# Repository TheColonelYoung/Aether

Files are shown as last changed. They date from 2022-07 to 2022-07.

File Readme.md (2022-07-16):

# AETHER
Addressable LED controller powered by WLED. Sound reactive capable with IR receiver. Due to ESP32 is capable to produce FFT effects.
Designed as replacement electronics for SP511e. So it fits the same case.

### Features and components
- Compatible with 12V and 5V strips
- Built-on digital microphone (INMP411) 
    - Works with Sound reactive fork
    - Support FFT effects
- IR receiver for remote control
- Bootloader jumper
- 3 buttons for manual control

### SP511e replacement
This project is designed as replacement for SP511e electronics which is based on ESP8266 which is not capable of FFT effect and can only driver one line of LED strips.
You don't need to have SP511e controller but some part are salvageable. You can 3D print your own case.
Microphone is also replaced with digital omni-directional which has better results.

Some parts are salvageable from original board:
- Cables for LEDs
- IR receiver with cable
- Buttons
- Input power jack
- Case

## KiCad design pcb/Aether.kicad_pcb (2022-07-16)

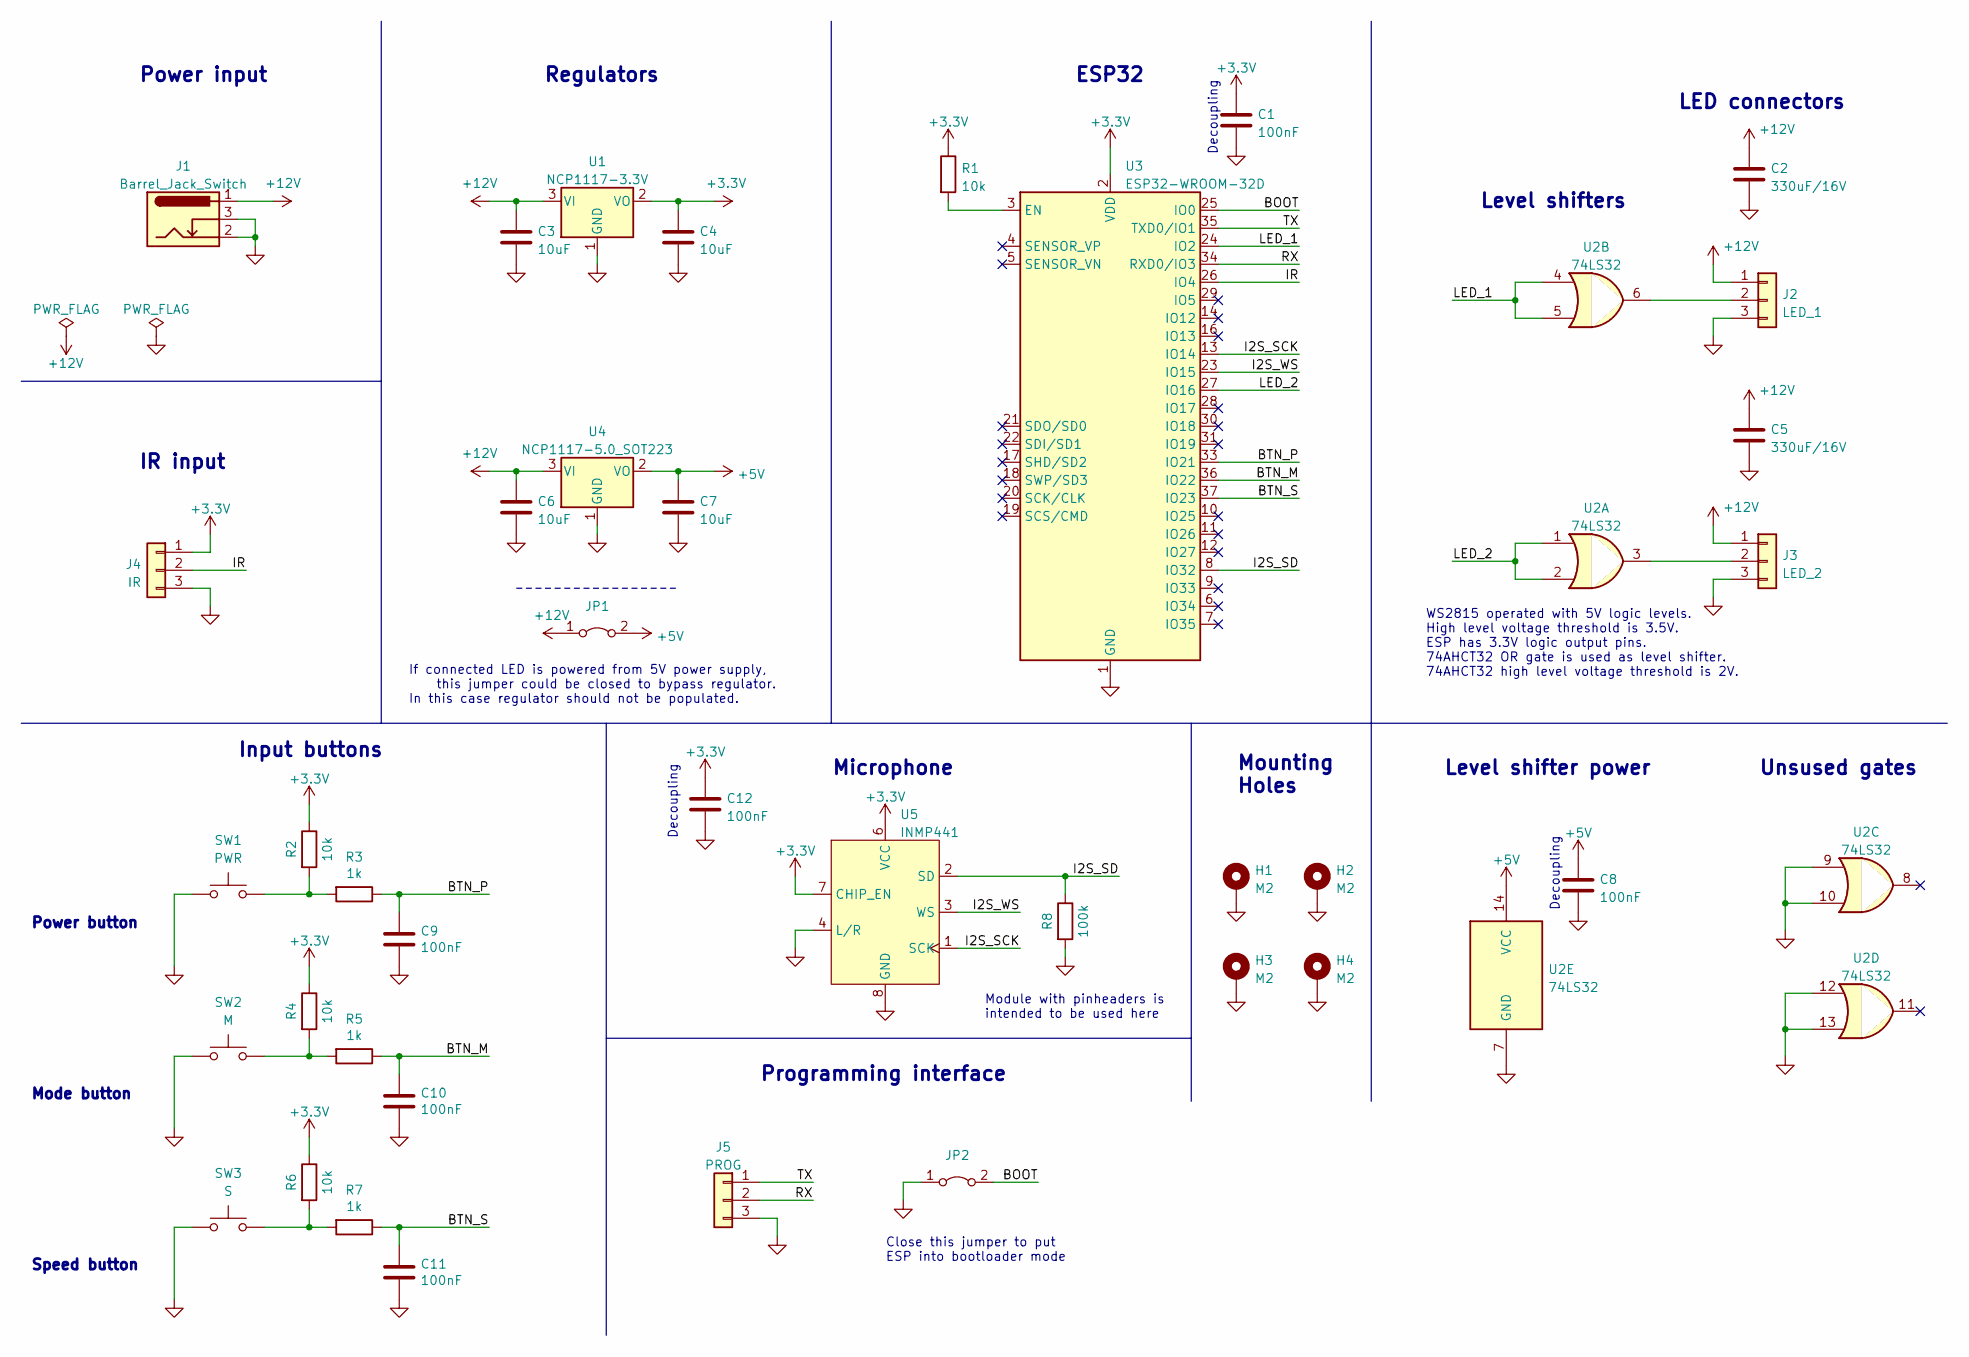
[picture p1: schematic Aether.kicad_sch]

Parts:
C1, C8, C9, C10, C11, C12: 100nF; C_0603_1608Metric
C2, C5: 330uF/16V; CP_Elec_6.3x7.7
C3, C4, C6, C7: 10uF; C_0805_2012Metric
H1, H2, H3, H4: M2; MountingHole_2.2mm_M2_Pad_Via
J1: Barrel_Jack_Switch; Barrel_jack_short
J2: LED_1; PinHeader_1x03_P2.54mm_Vertical
J3: LED_2; PinHeader_1x03_P2.54mm_Vertical
J4: IR; PinHeader_1x03_P2.54mm_Vertical
J5: PROG; PinHeader_1x03_P2.54mm_Vertical
JP1: 5V_PASSTHROUGH; SolderJumper-2_P1.3mm_Open_RoundedPad1.0x1.5mm
JP2: BOOT; PinHeader_1x02_P2.54mm_Vertical
R1, R2, R4, R6: 10k; R_0603_1608Metric
R3, R5, R7: 1k; R_0603_1608Metric
R8: 100k; R_0603_1608Metric
SW1: PWR; SW_SPST_TL3342
SW2: M; SW_SPST_TL3342
SW3: S; SW_SPST_TL3342
U1: NCP1117-3.3V; SOT-223-3_TabPin2
U2: 74LS32; Texas_S-PVQFN-N14
U3: ESP32-WROOM-32D; ESP32-WROOM-32
U4: NCP1117-5.0_SOT223; SOT-223-3_TabPin2
U5: INMP441

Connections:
+3.3V: C1.1, C4.1, C12.1, J4.1, R1.1, R2.1, R4.1, R6.1, U1.2 (VO), U3.2 (VDD), U5.6 (VCC), U5.7 (CHIP_EN)
+5V: C7.1, C8.1, JP1.2 (B), U2.14 (VCC), U4.2 (VO)
+12V: C2.1, C3.1, C5.1, C6.1, J1.1, J2.1, J3.1, JP1.1 (A), U1.3 (VI), U4.3 (VI)
/BOOT: JP2.2 (B), U3.25 (IO0)
/BTN_M: C10.1, R5.1, U3.36 (IO22)
/BTN_P: C9.1, R3.1, U3.33 (IO21)
/BTN_S: C11.1, R7.1, U3.37 (IO23)
/I2S_SCK: U3.13 (IO14), U5.1 (SCK)
/I2S_SD: R8.1, U3.8 (IO32), U5.2 (SD)
/I2S_WS: U3.23 (IO15), U5.3 (WS)
/IR: J4.2, U3.26 (IO4)
/LED_1: U2.4, U2.5, U3.24 (IO2)
/LED_2: U2.1, U2.2, U3.27 (IO16)
/RX: J5.2, U3.34 (RXD0/IO3)
/TX: J5.1, U3.35 (TXD0/IO1)
GND: C1.2, C2.2, C3.2, C4.2, C5.2, C6.2, C7.2, C8.2, C9.2, C10.2, C11.2, C12.2, H1.1, H2.1, H3.1, H4.1, J1.2, J1.3, J2.3, J3.3, J4.3, J5.3, JP2.1 (A), R8.2, SW1.1, SW2.1, SW3.1, U1.1 (GND), U2.7 (GND), U2.9, U2.10, U2.12, U2.13, U3.1 (GND), U3.15 (GND), U3.38 (GND), U3.39 (GND), U4.1 (GND), U5.4 (L/R), U5.5 (GND), U5.8 (GND), U5.9 (GND)
unnamed: J2.2, U2.6
unnamed: J3.2, U2.3
unnamed: R1.2, U3.3 (EN)
unnamed: R2.2, R3.2, SW1.2
unnamed: R4.2, R5.2, SW2.2
unnamed: R6.2, R7.2, SW3.2

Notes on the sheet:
Regulators
IR input
WS2815 operated with 5V logic levels. High level voltage threshold is 3.5V. ESP has 3.3V logic output pins. 74AHCT32 OR gate is used as level shifter. 74AHCT32 high level voltage threshold is 2V.
Decoupling
Level shifter power
Input buttons
Power button
Level shifters
Programming interface
LED connectors
ESP32
Mounting Holes
Power input
Close this jumper to put ESP into bootloader mode
Microphone
If connected LED is powered from 5V power supply, this jumper could be closed to bypass regulator. In this case regulator should not be populated.
Module with pinheaders is intended to be used here
Unsused gates
Speed button
Mode button

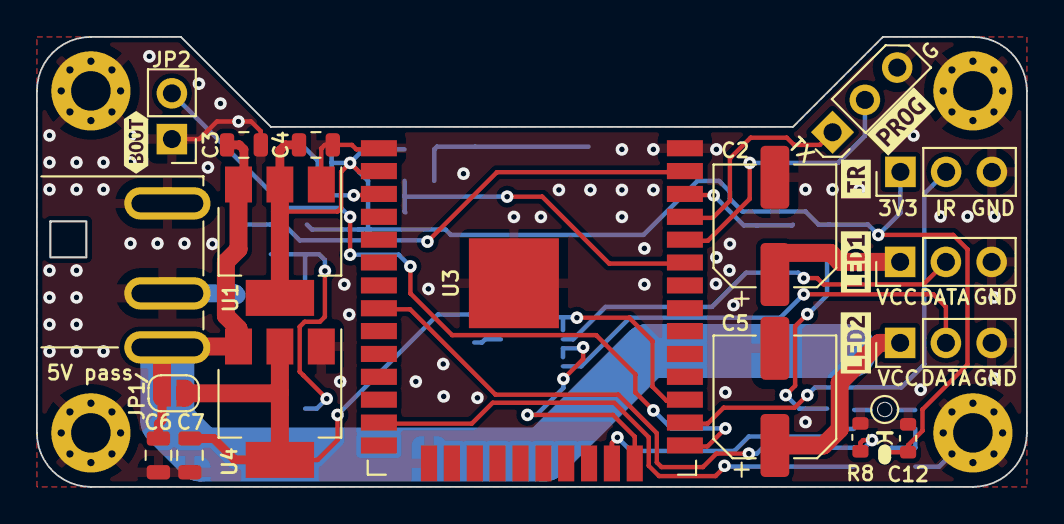
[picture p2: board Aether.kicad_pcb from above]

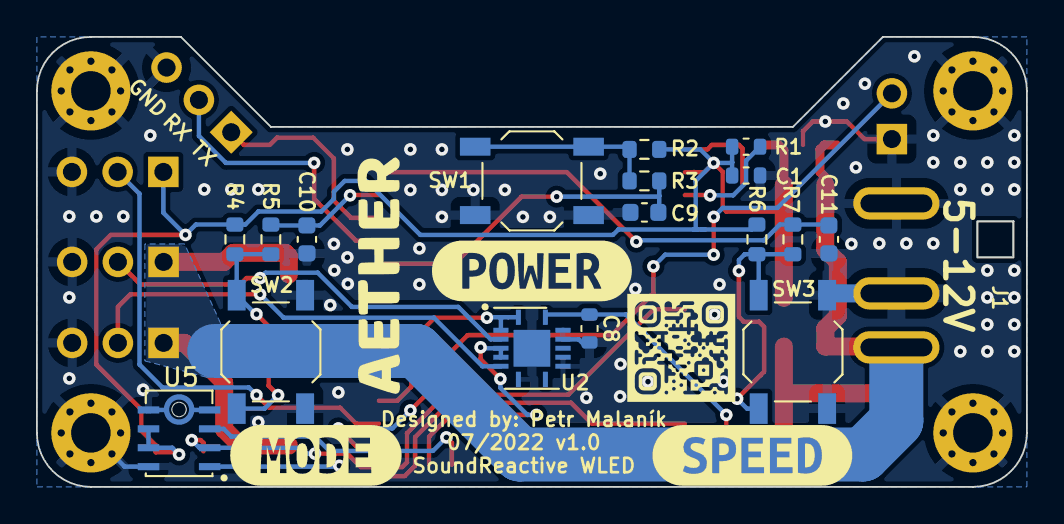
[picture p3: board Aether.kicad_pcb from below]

Board: 2 copper layers, 55.0 x 25.0 mm, 47 parts (20 on the bottom side), 22 nets.

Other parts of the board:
kibuzzard-62D1B70F: G***; kibuzzard-62D1B70F
kibuzzard-62D1B640: G***; kibuzzard-62D1B640
kibuzzard-62D1B654: G***; kibuzzard-62D1B654
kibuzzard-62D1B701: G***; kibuzzard-62D1B701
kibuzzard-62D2D12D: G***; kibuzzard-62D2D12D
kibuzzard-62D13E5B: G***; kibuzzard-62D13E5B
kibuzzard-62D13E43: G***; kibuzzard-62D13E43
kibuzzard-62D13E62: G***; kibuzzard-62D13E62

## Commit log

2022-07-11 Schema: Initial parts selection
    [Aether.kicad_pcb, Aether.kicad_sch]
2022-07-14 Schema: add level shifter, microphone and second LED output
    [Aether.kicad_sch]
2022-07-16 Schema: add microphone, mounting holes and finalize buttons
    [Aether.kicad_sch]
2022-07-16 PCB: Done routing of board
    [Aether.kicad_pcb]
2022-07-16 Project: move PCB sources into pcb folder, create Readme
    [Aether.kicad_pcb, Aether.kicad_sch]
